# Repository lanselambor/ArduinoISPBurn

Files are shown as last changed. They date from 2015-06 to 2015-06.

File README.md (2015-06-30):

# Arduino ISP programmer  <br>
Using Arduino Mega 2560 burning bootloader to another Arduino board.<br>

## Usage <br>
### **1.Board assambling** <br>
* Arduino Mega2560 + SD card Shield + Base Shield <br>

### **2.Download and unzip*** <br>
* Download this repository.
* Unzip files within the folder libraries out to Arduino libraries.

### **3.Operation** <br>
* SD card init successfully with Green led on. <br>
* Press button roll to change program. <br>
* Press button start to begin burning program. <br>
* Red led on while burning. <br>
* Red led off and green led on if burning succeeded.

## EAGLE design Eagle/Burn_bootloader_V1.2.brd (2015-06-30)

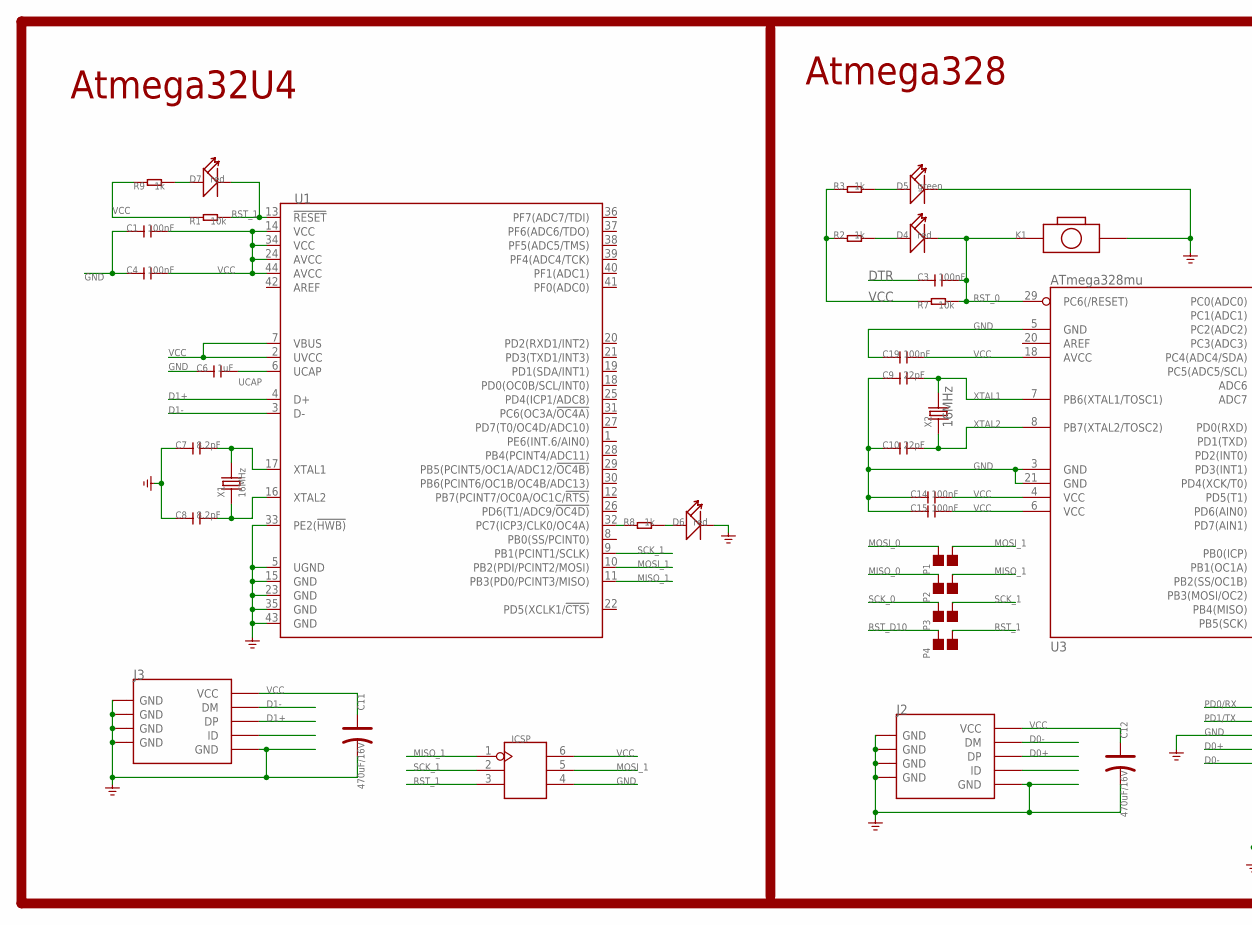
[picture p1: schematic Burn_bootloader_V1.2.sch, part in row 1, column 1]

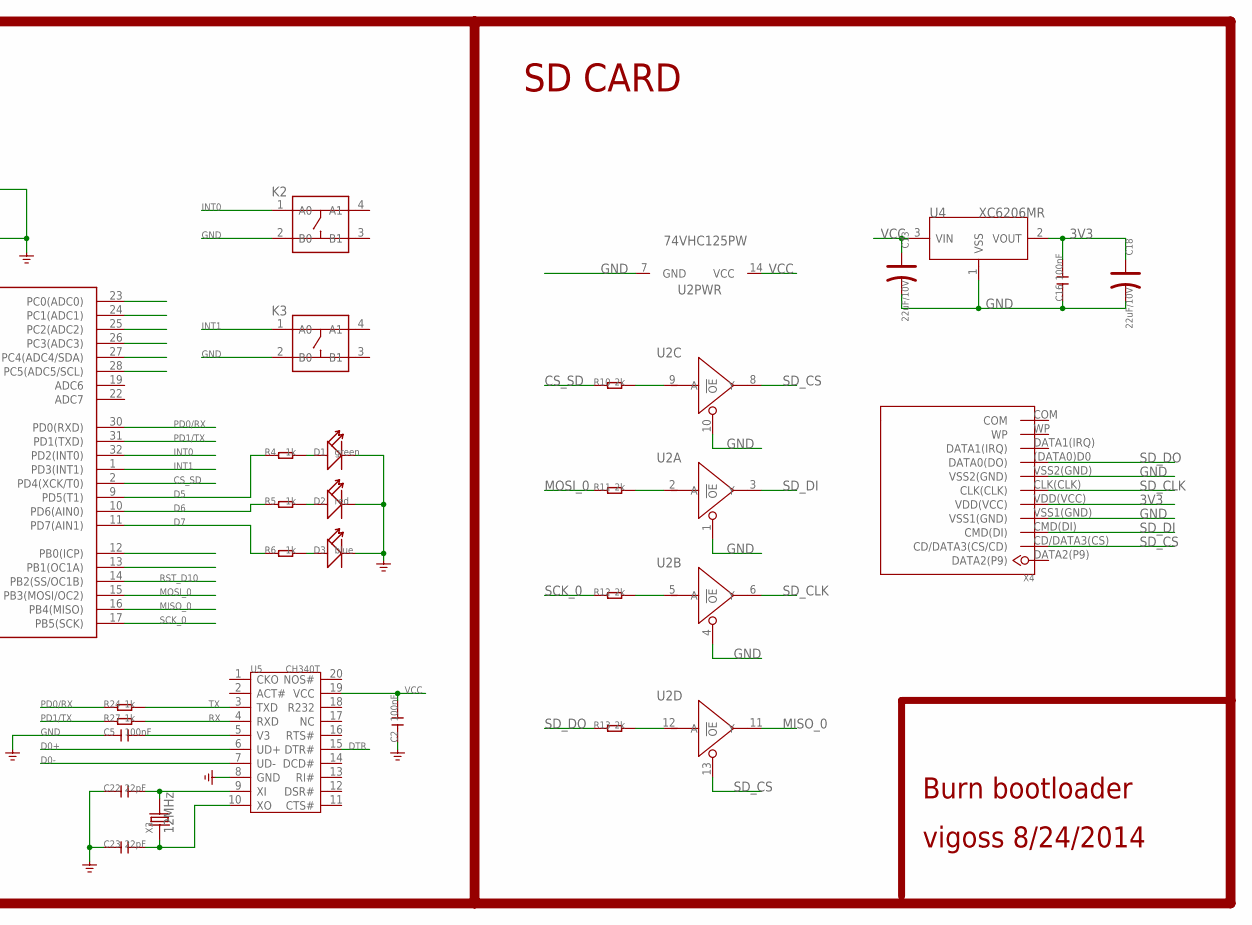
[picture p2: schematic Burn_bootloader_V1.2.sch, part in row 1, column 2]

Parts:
C1, C2, C3, C4, C5, C14, C15, C19: 100nF; C0603
C6: 1uF; C0603
C7, C8: 8.2pF; C0603
C9, C10, C22, C23: 22pF; C0603
C11, C12: 470uF/16V; AVX-C
C13, C18: 22uF/10V; AVX-A
C16: 100nF; C0805
D1: green; LED-2P-2.54-6MM
D2: red; LED-2P-2.54-6MM
D3: blue; LED-2P-2.54-6MM
D4, D6, D7: red; LED-0603
D5: green; LED-0603
ICSP: HEADER-2X3P-2.54; 2X3P-2.54
J2, J3: USB-MINIUSB-5P-STRONG; MINI-SMD-5P
K1: BUTTON-2P'TS-1101F'; 2P-3.4X6.0X3.55H-90D
K2, K3: BUTTON-4P-6.2X6.2; 4P-6.2X6.2
P1, P2, P3, P4: PAD-JUMPER-2P; 2P-SMD-1.78X1.27
R1, R7: 10k; R0603
R2, R3, R4, R5, R6, R8, R9, R24, R27: 1k; R0603
R10, R11, R12, R13: 2k; R0603
U1: MCU-ATMEGA32U4; TEST-VQFN-44
U2: 74VHC125PW; TSSOP14
U3: ATmega328mu; TQFP32
U4: XC6206MR; SOT23
U5: CH340T; SSOP20
X1, X2: 16MHz; 2P-SMD-5X3.2
X3: 12MHz; 2P-SMD-5X3.2
X4: SDCARDEXTDEVICE; SDCARDEXTPACKAGE

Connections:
3V3: C16.2, C18.+, U4.2 (VOUT), X4.VDD(VCC)
CS_SD: R10.1, U3.2 (PD4(XCK/T0))
D0+: J2.3 (DP), U5.6 (UD+)
D0-: J2.2 (DM), U5.7 (UD-)
D1+: J3.3 (DP), U1.4 (D+)
D1-: J3.2 (DM), U1.3 (D-)
D5: R4.1, U3.9 (PD5(T1))
D6: R5.1, U3.10 (PD6(AIN0))
D7: R6.1, U3.11 (PD7(AIN1))
DTR: C3.1, U5.15 (DTR#)
GND: C1.1, C2.1, C4.1, C5.1, C6.1, C7.1, C8.1, C9.1, C10.1, C11.-, C12.-, C13.-, C14.1, C15.1, C16.1, C18.-, C19.1, C22.1, C23.1, D1.-, D2.-, D3.-, D5.-, D6.-, ICSP.4, J2.5 (GND), J2.GND@1 (GND), J2.GND@2 (GND), J2.GND@3 (GND), J2.GND@4 (GND), J3.5 (GND), J3.GND@1 (GND), J3.GND@2 (GND), J3.GND@3 (GND), J3.GND@4 (GND), K1.P$2 (2), K2.2 (B0), K3.2 (B0), U1.5 (UGND), U1.15 (GND), U1.23 (GND), U1.33 (PE2(!HWB)), U1.35 (GND), U1.43 (GND), U2.1 (!OE), U2.4 (!OE), U2.7 (GND), U2.10 (!OE), U3.3 (GND), U3.5 (GND), U3.21 (GND), U4.1 (VSS), U5.8 (GND), X4.VSS1(GND), X4.VSS2(GND)
INT0: K2.1 (A0), U3.32 (PD2(INT0))
INT1: K3.1 (A0), U3.1 (PD3(INT1))
MISO_0: P2.2, U2.11 (Y), U3.16 (PB4(MISO))
MISO_1: ICSP.1, P2.1, U1.11 (PB3(PD0/PCINT3/MISO))
MOSI_0: P1.2, R11.1, U3.15 (PB3(MOSI/OC2))
MOSI_1: ICSP.5, P1.1, U1.10 (PB2(PDI/PCINT2/MOSI))
unnamed: D1.+, R4.2
unnamed: D2.+, R5.2
unnamed: D4.+, R2.2
unnamed: D5.+, R3.2
unnamed: D3.+, R6.2
unnamed: R8.1, U1.32 (PC7(ICP3/CLK0/OC4A))
unnamed: D6.+, R8.2
unnamed: D7.+, R9.2
unnamed: C7.2, U1.17 (XTAL1), X1.2
unnamed: C8.2, U1.16 (XTAL2), X1.1
unnamed: R13.2, U2.12 (A)
unnamed: R12.2, U2.5 (A)
unnamed: R11.2, U2.2 (A)
unnamed: R10.2, U2.9 (A)
unnamed: C22.2, U5.9 (XI), X3.2
unnamed: C23.2, U5.10 (XO), X3.1
PD0/RX: R24.1, U3.30 (PD0(RXD))
PD1/TX: R27.1, U3.31 (PD1(TXD))
RST_0: C3.2, D4.-, K1.P$1 (1), R7.2, U3.29 (PC6(/RESET))
RST_1: D7.-, ICSP.3, P4.1, R1.2, U1.13 (!RESET)
RST_D10: P4.2, U3.14 (PB2(SS/OC1B))
RX: R27.2, U5.4 (RXD)
SCK_0: P3.2, R12.1, U3.17 (PB5(SCK))
SCK_1: ICSP.2, P3.1, U1.9 (PB1(PCINT1/SCLK))
SD_CLK: U2.6 (Y), X4.CLK(CLK)
SD_CS: U2.8 (Y), U2.13 (!OE), X4.CD/DATA3(CS) (CD/DATA3(CS/CD))
SD_DI: U2.3 (Y), X4.CMD(DI)
SD_DO: R13.1, X4.(DATA0)D0 (DATA0(DO))
TX: R24.2, U5.3 (TXD)
UCAP: C6.2, U1.6 (UCAP)
V3: C5.2, U5.5 (V3)
VCC: C1.2, C2.2, C4.2, C11.+, C12.+, C13.+, C14.2, C15.2, C19.2, ICSP.6, J2.1 (VCC), J3.1 (VCC), R1.1, R2.1, R3.1, R7.1, R9.1, U1.2 (UVCC), U1.7 (VBUS), U1.14 (VCC), U1.24 (AVCC), U1.34 (VCC), U1.44 (AVCC), U2.14 (VCC), U3.4 (VCC), U3.6 (VCC), U3.18 (AVCC), U4.3 (VIN), U5.19 (VCC)
XTAL1: C9.2, U3.7 (PB6(XTAL1/TOSC1)), X2.2
XTAL2: C10.2, U3.8 (PB7(XTAL2/TOSC2)), X2.1

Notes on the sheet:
Atmega32U4
Atmega328
SD CARD
Burn bootloader
vigoss 8/24/2014

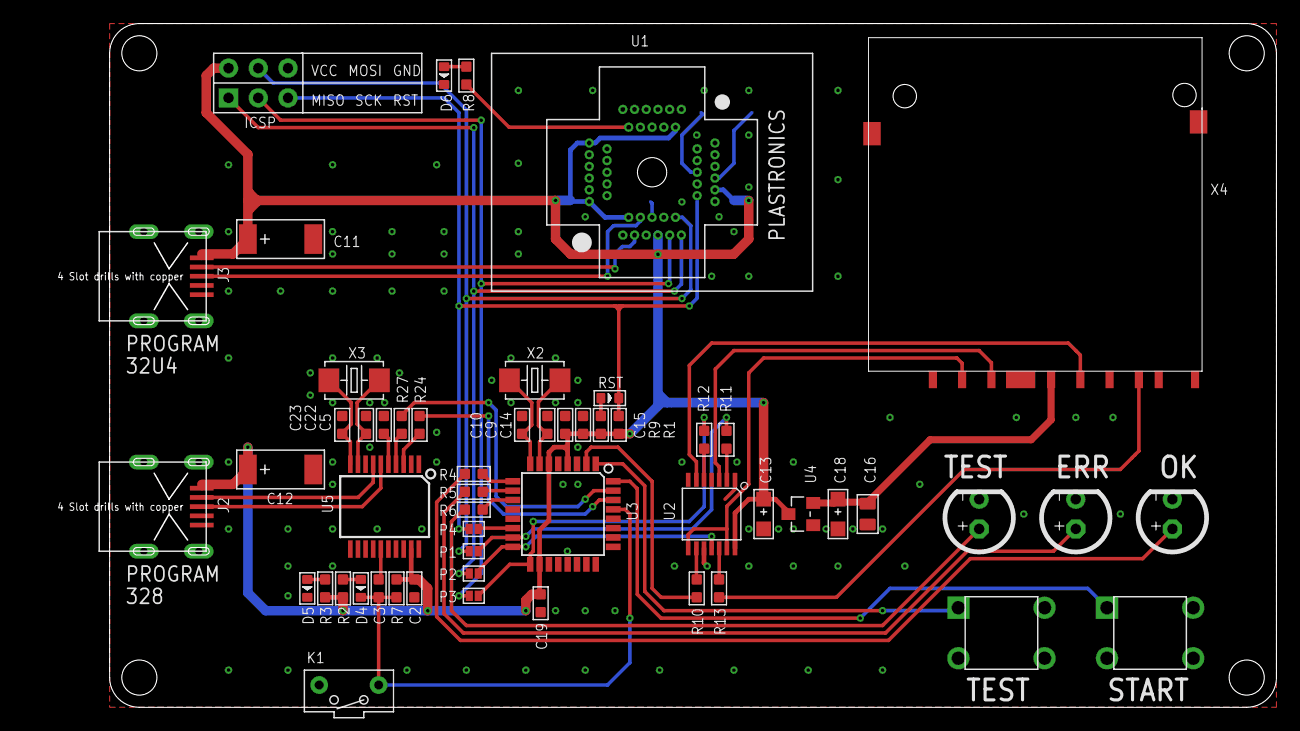
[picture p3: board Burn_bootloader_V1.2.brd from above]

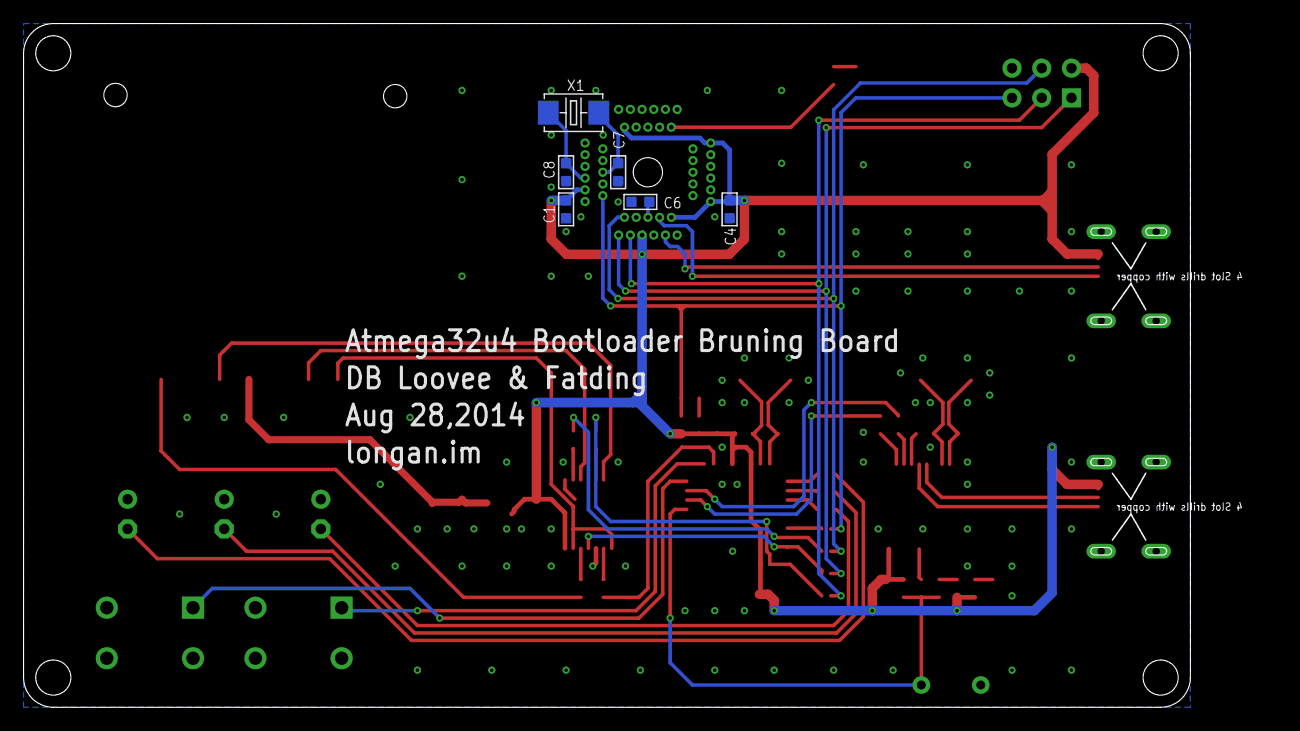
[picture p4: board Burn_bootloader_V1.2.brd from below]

Board: 2 copper layers, 99.7 x 58.4 mm, 61 parts (6 on the bottom side), 51 nets.
